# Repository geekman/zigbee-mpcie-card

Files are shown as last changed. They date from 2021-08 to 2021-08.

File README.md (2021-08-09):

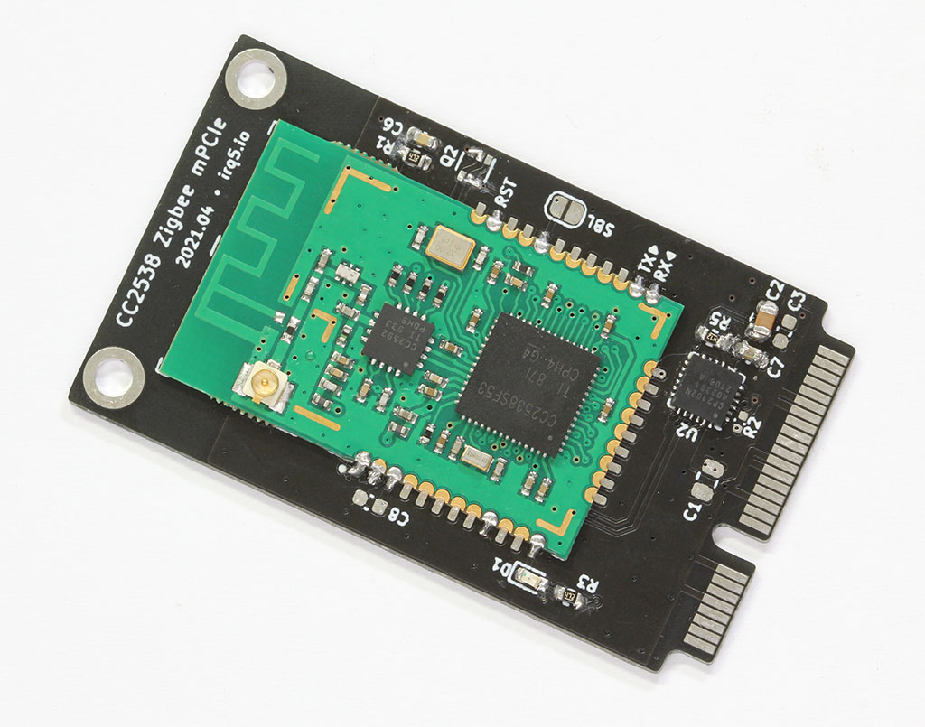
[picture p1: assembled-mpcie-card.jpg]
photo of the assembled CC2538 Zigbee mPCIe card


CC2538 Zigbee mPCIe Adapter
============================

For use with [zigbee2mqtt](https://www.zigbee2mqtt.io/).

This card is basically a USB-to-serial adapter for the CC2538 + CC2592 PA Zigbee module.
It is intended for use in host devices that accept mPCIe cards, instead of having a Zigbee dongle sticking out of the USB port.
The antenna connection is also brought out to an external SMA connector via a U.FL pigtail.

As with most of my boards, this was designed to be flexible. The TX and RX pins from the module are clearly marked, so that the card can be repurposed as a generic serial device mPCIe card.
There are also various test points for I²C, as well as control for the WLAN/WWAN LEDs that are on the host machine.

This project is authored in [KiCad EDA](https://www.kicad.org/).
You can find schematics and the BOM under the [Releases](https://github.com/geekman/zigbee-mpcie-card/releases) section.

Assembly Instructions
======================

Please be aware that there are a few variations of this CC2538 module with different pinouts and dimensions.
The one I bought, and used in this mPCIe card, is available on [AliExpress here](https://www.aliexpress.com/item/4000748032872.html).
Also note that the presence of an on-board antenna; the module needs to be physically configured to use the U.FL connector instead of the on-board antenna.
You will need to indicate this to the seller, or you can modify it yourself by moving a capacitor (or resistor, not sure what that part is).

The card has support for native USB connectivity to the CC2538, but it is not used. 
As such, the component on the back side should not be populated, as well as R2 on the front side. The BOM file has these parts marked as DNP.

Additionally, Q2 was added for an ESP8266-style auto reset, but since the `cc2538-bsl` does not support this style of bootloader invocation, the pins of Q2 need to be manually bridged. The new revision of PCB has these connections marked out on the silkscreen.

Testing
--------

When inserted, the card should be detected as a CP2102N USB device on the host.

You need the [cc2538-bsl](https://github.com/JelmerT/cc2538-bsl) Python tool, 
which only depends on `pyserial`.
Note that the tool will try to reconnect to the port with an increased baud rate for faster transfer speeds, but this was causing problems for me. Use `-b` to set a fixed baud rate, and choose a lower value for stability.

You can test that the mPCIe card is properly detected by reading from the CC2538 with `-r`:

```
$ python3 cc2538-bsl.py -b 500000 -r test.bin
Opening port /dev/ttyUSB0, baud 500000
Connecting to target...
CC2538 PG2.0: 512KB Flash, 32KB SRAM, CCFG at 0x0027FFD4
Primary IEEE Address: 00:12:4B:00:19:4A:F1:CE
Reading 524288 bytes starting at address 0x200000
 0x200xxx: 0xffffffff
```

If you do specify the `-V` verbose flag, you see that chip ID for the CC2538 has been correctly detected:

```
$ python3 cc2538-bsl.py -V -r test.bin
Opening port /dev/ttyUSB0, baud 500000
Connecting to target...
*** sending synch sequence
Got 0 additional bytes before ACK/NACK
*** GetChipId command (0x28)
Got 0 additional bytes before ACK/NACK
*** received 6 bytes
*** GetStatus command (0x23)
Got 0 additional bytes before ACK/NACK
*** received 3 bytes
Command Successful
    Version 0x0000B964
    Target id 0xb964, CC2538
  .
  .
  .
```

Firmware Flashing
==================

You can download a zigbee2mqtt-compatible firmware here:

- <https://github.com/jethome-ru/zigbee-firmware/tree/master/ti/coordinator/cc2538_cc2592>

Here are some other firmware for reference:

- <https://github.com/egony/MODKAM-STICK-V3/tree/master/firmware/cc2538/Riverieline_2020-02>
- <https://github.com/Koenkk/Z-Stack-firmware/tree/master/coordinator>

You can choose either one; I went with the JetHome one.

Use the `cc2538-bsl.py` tool with `-w -v` to write and verify the firmware file.
Both the `.bin` and `.hex` contain the same firmware, just in a different format.

```
$ python3 cc2538-bsl.py -b 115200 -w -v JH_2538_2592_ZNP_UART_20201010.bin
Opening port /dev/ttyUSB0, baud 115200
Reading data from JH_2538_2592_ZNP_UART_20201010.bin
Cannot auto-detect firmware filetype: Assuming .bin
Connecting to target...
CC2538 PG2.0: 512KB Flash, 32KB SRAM, CCFG at 0x0027FFD4
Primary IEEE Address: 00:12:4B:00:19:4A:F1:CE
Writing 524256 bytes starting at address 0x00200000
Write 232 bytes at 0x0027FEF88
    Write done
Verifying by comparing CRC32 calculations.
    Verified (match: 0x6273805e)
```

You should now see the power LED on the mPCIe card light up.

Bootloader "Backdoor"
----------------------

Note that while the serial bootloader is a convenient way to program the CC2538, it may also be disabled by the firmware developer for security reasons.

The firmware images provided above all have this "bootloader backdoor" enabled, so that newer firmware can be flashed via the serial port.
This is done by setting some bits in the Customer Configuration Area (CCA) to enable the backdoor, and allowing for activation via pin `PA7`.
For more information, see the SWRA466 document here: <https://www.ti.com/lit/pdf/swra466>

You can verify this by opening the firmware HEX file and seeing the value `0xF7` set at `0x0027.FFD7`. (Actually the write begins at `0x27FFD4` to write a 32-bit value `FF FF FF F7`)

If you do not flash these bytes into the CCA, the serial bootloader can no longer be accessed and you will need JTAG to program the device. The connector has been brought out to the back side of the card, in case this is needed.

License
========
  
**cc2538-mpcie-card is licensed under the TAPR Open Hardware License (https://www.tapr.org/OHL).**

Copyright (C) 2021 Darell Tan

The TAPR Open Hardware License ("OHL") agreement provides a legal
framework for Open Hardware projects.
The OHL addresses unique issues involved in the creation of tangible,
physical things, but does not cover software, firmware, or code loaded
into programmable devices.

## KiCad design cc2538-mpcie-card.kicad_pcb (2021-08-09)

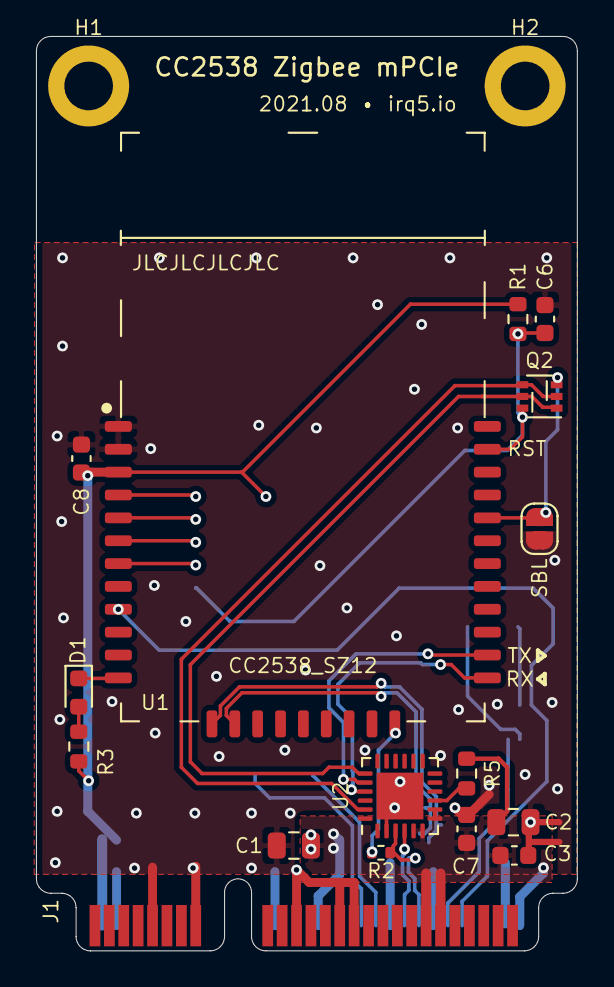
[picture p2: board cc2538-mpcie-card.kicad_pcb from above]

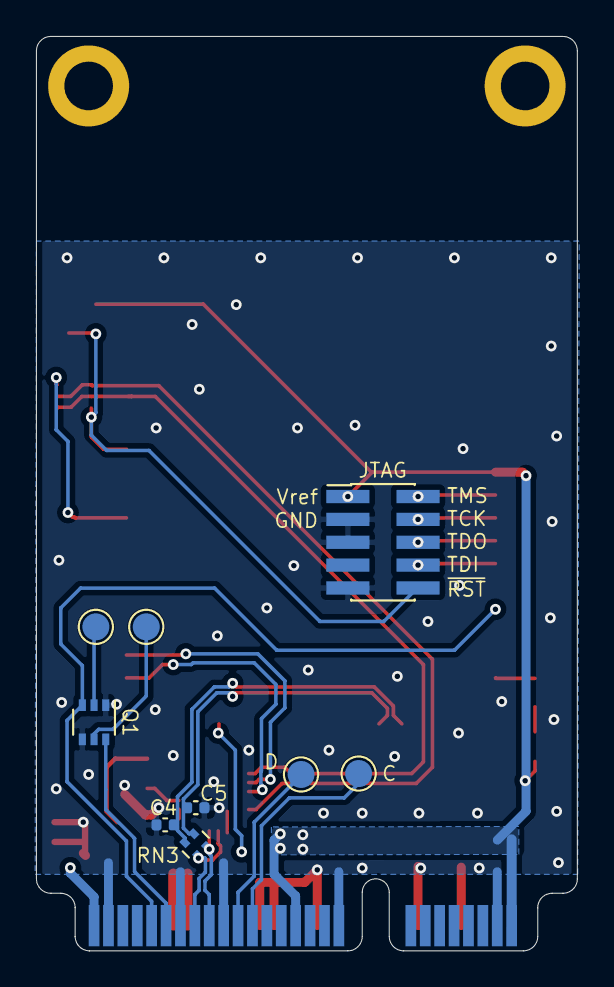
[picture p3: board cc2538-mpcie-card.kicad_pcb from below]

Board: 2 copper layers, 30.1 x 50.8 mm, 27 parts (9 on the bottom side), 26 nets.

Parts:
C1, C2: 47uF; C_0805_2012Metric
C3, C7: 0.1uF; C_0603_1608Metric
C4, C5: 47pF; C_0402_1005Metric
C6: 1nF; C_0603_1608Metric
C8: 10uF; C_0603_1608Metric
D1: LED_Small; LED_0603_1608Metric
H1, H2: MountingHole_Pad; MountingHole_2.7mm_M2.5_ISO7380_Pad
J1: Bus_PCI_Express_Mini; mPCIe_Card_Edge
J2: Conn_ARM_JTAG_SWD_10; PinHeader_2x05_P1.27mm_Vertical_SMD
JP1: SolderJumper_2_Open; SolderJumper-2_P1.3mm_Open_RoundedPad1.0x1.5mm
Q1, Q2: MUN5214DW1; SOT-363_SC-70-6
R1, R3, R5: 4K7; R_0603_1608Metric
R2: 1K5; R_0402_1005Metric
RN3: 33R; R_Array_Convex_2x0402
TP1: SDA; TestPoint_Pad_D1.5mm
TP2: SCL; TestPoint_Pad_D1.5mm
TP3: LED_WLAN; TestPoint_Pad_D1.5mm
TP4: LED_WWAN; TestPoint_Pad_D1.5mm
U1: CC2538_SZ12; CC2538_SZ12_Module
U2: CP2102N-A01-GQFN24; QFN-24-1EP_4x4mm_P0.5mm_EP2.6x2.6mm

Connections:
+3V3: C1.1, C2.1, C3.1, C7.2, C8.2, J1.2, J1.24, J1.39, J1.41, J1.52, J2.1, R1.2, R3.2, R5.1, U1.3, U2.5, U2.6, U2.7, U2.8
/CC_RST: C6.2, J2.10, Q2.6, R1.1, U1.32
/CC_RX: U1.22, U2.21
/CC_SBL: JP1.1, Q2.3, U1.29
/CC_TX: U1.23, U2.20
/CC_USB+: C4.1, RN3.4, U1.13
/CC_USB-: C5.2, RN3.3, U1.14
/USB+: J1.38, R2.2, RN3.1, U2.3
/USB-: J1.36, RN3.2, U2.4
/USB_FS_PU: R2.1, U1.21
/~LED_ACT: J1.44, Q1.3, U1.9
/~LED_PWR: D1.1, U1.12
/~LED_WWAN: J1.42, Q1.6
GND: C1.2, C2.2, C3.2, C4.2, C5.1, C6.1, C7.1, C8.1, J1.4, J1.9, J1.15, J1.18, J1.21, J1.26, J1.27, J1.29, J1.34, J1.35, J1.37, J1.40, J1.43, J1.50, J2.3, J2.5, J2.9, JP1.2, Q1.1, Q1.4, U1.1, U1.2, U2.2, U2.25
unnamed: D1.2, R3.1
unnamed: J1.30, TP2.1
unnamed: J1.32, TP1.1
unnamed: J2.2, U1.4
unnamed: J2.4, U1.5
unnamed: J2.6, U1.6
unnamed: J2.8, U1.7
unnamed: Q1.2, TP4.1
unnamed: Q1.5, TP3.1
unnamed: Q2.1, Q2.5, U2.19
unnamed: Q2.2, Q2.4, U2.23
unnamed: R5.2, U2.9

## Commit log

2021-04-16 Initial layout complete.
    [cc2538-mpcie-card.kicad_pcb, cc2538-mpcie-card.sch]
2021-04-16 Reworked USB, added power LED & cap
    The USB conection used to have dangling stubs, due to the likely
    unpopulated direct connection to the CC2538 native USB. It has now been
    reworked to use 0402 components, and the series resistor now rests
    directly on the vias, minimizing the amount of stub. Although it's just
    low speed USB, I doubt it would affect much.
    Additionally, wired up the activity LED (PB4) to the system's WLAN
    indicator, and added a power LED (PB1), which would be turned on by the
    module to indicate it's alive.
    Also added a capacitor near the module's 3V3 connection.
    [cc2538-mpcie-card.kicad_pcb, cc2538-mpcie-card.sch]
2021-04-16 Added PCB markings & text
    - Labelled pinout for JTAG connector
    - Added PCB "title" & date
    - Added PCB manufacturer number marker
    [cc2538-mpcie-card.kicad_pcb]
2021-04-16 Added PCB dimension markings
    [cc2538-mpcie-card.kicad_pcb]
2021-04-17 Made card edge component "virtual"
    This prevents it from showing up in the BOM.
    [cc2538-mpcie-card.kicad_pcb]
2021-04-17 Fix up component values
    [cc2538-mpcie-card.kicad_pcb, cc2538-mpcie-card.sch]
2021-04-24 Added document title & rev, and more GND vias
    [cc2538-mpcie-card.kicad_pcb]
2021-04-25 Totally forgot to connect RXD/TXD serial lines
    [cc2538-mpcie-card.kicad_pcb, cc2538-mpcie-card.sch]
2021-04-25 Added RX/TX marking to module
    [cc2538-mpcie-card.kicad_pcb]
2021-04-25 Marking for SCL should be C(lock)
    [cc2538-mpcie-card.kicad_pcb]
2021-04-26 Updated Gerber generation settings
    [cc2538-mpcie-card.kicad_pcb]
2021-07-29 Made curves 0.8mm radius, instead of 0.5mm
    After receiving the first batch of prototype boards, the curves don't
    look very prominent -- still a bit sharp on the corners. Not sure if
    that's attributed to the manufacturing process, but I thought I'd
    increase the curve radius to make it smoother.
    [cc2538-mpcie-card.kicad_pcb]
2021-07-29 Increased GND plane clearance to 0.35mm
    The current GND plane is too near the edge in the prototype boards.
    Increased the clearance because it is unnecessary to have such a tight
    clearance for the GND plane anyway.
    [cc2538-mpcie-card.kicad_pcb]
2021-08-08 Reduce thermal spokes to 0.3mm
    Found it difficult to solder the GND pins of the Zigbee module. I'm not
    sure if the heat was being conducted away by the GND plane on the
    castellated GND pads of the module, or by the GND plane on this board.
    In either case, it's safer to just reduce the spoke widths of the copper
    pours, since 0.508mm for thermal spokes is an overkill anyway. In
    addition, thermal clearance is also increased to pull the pours away
    from the pad, hopefully reducing thermal conduction.
    [cc2538-mpcie-card.kicad_pcb]
2021-08-08 Standardize resistors to 4K7
    The LED can also use 4K7 (whether red or green) since it should be
    bright enough.
    Additionally, clarify that C6 (RST cap) must be 1nF max in order not to
    interfere with software reset via the CP2012. It looks like the Python
    script doesn't have any delays when toggling the RTS pin, so we
    shouldn't use anything higher (like 100nF for C7).
    [cc2538-mpcie-card.sch]
2021-08-09 Added Q2 bridge silkscreen & some schematic text
    [cc2538-mpcie-card.kicad_pcb, cc2538-mpcie-card.sch]
2021-08-09 Added DNP field to schematic
    This marks out the components that we added for the "dev board"
    functionality, and native USB parts.
    1 - DNP
    2 - populate for native USB
    [cc2538-mpcie-card.sch]
2021-08-09 Updated PCB, bumped revision numbers
    [cc2538-mpcie-card.kicad_pcb, cc2538-mpcie-card.sch]
